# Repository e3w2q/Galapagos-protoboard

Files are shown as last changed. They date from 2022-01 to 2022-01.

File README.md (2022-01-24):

# Galapagos Protoboard

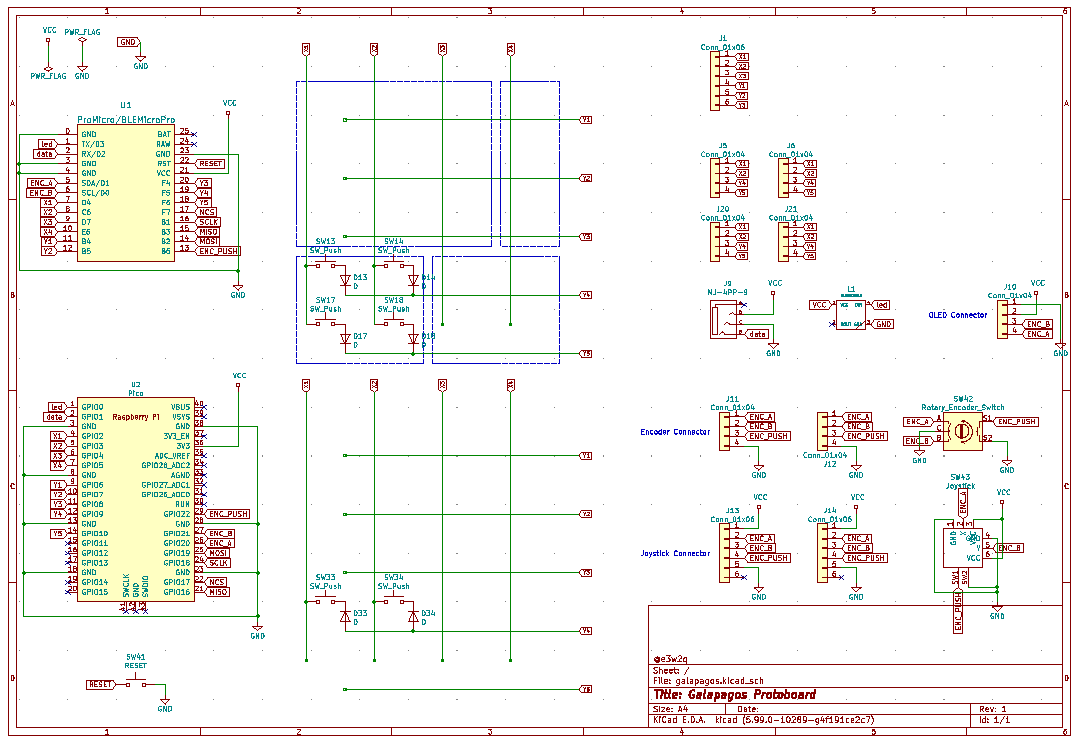
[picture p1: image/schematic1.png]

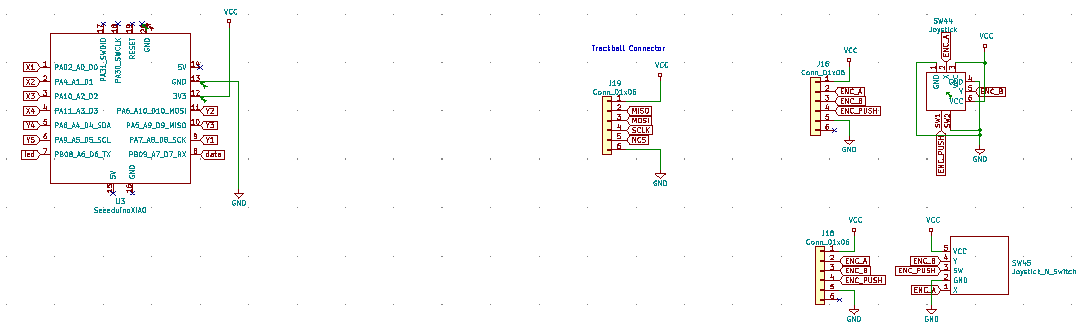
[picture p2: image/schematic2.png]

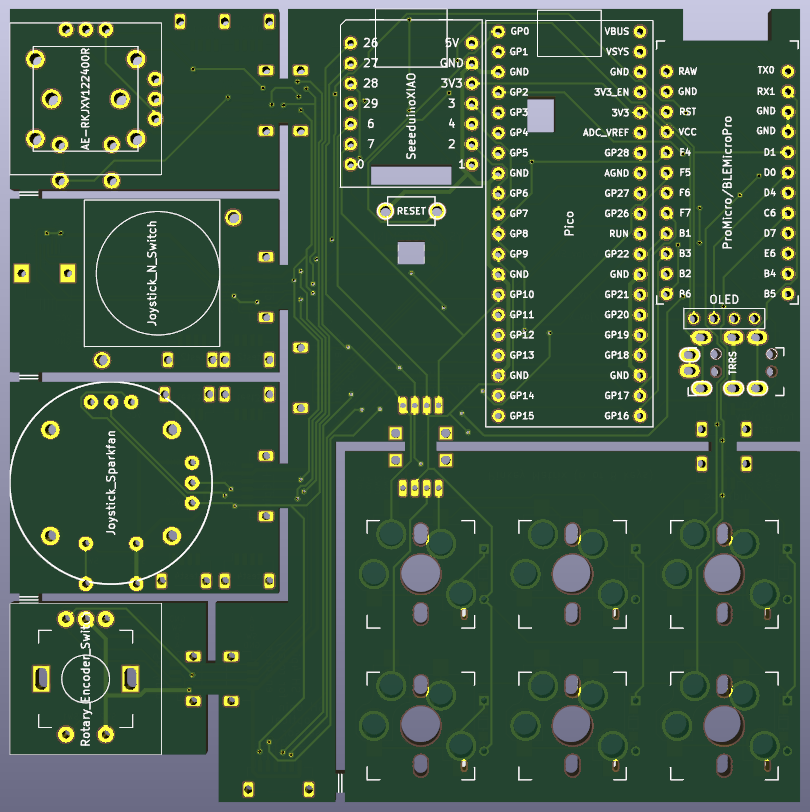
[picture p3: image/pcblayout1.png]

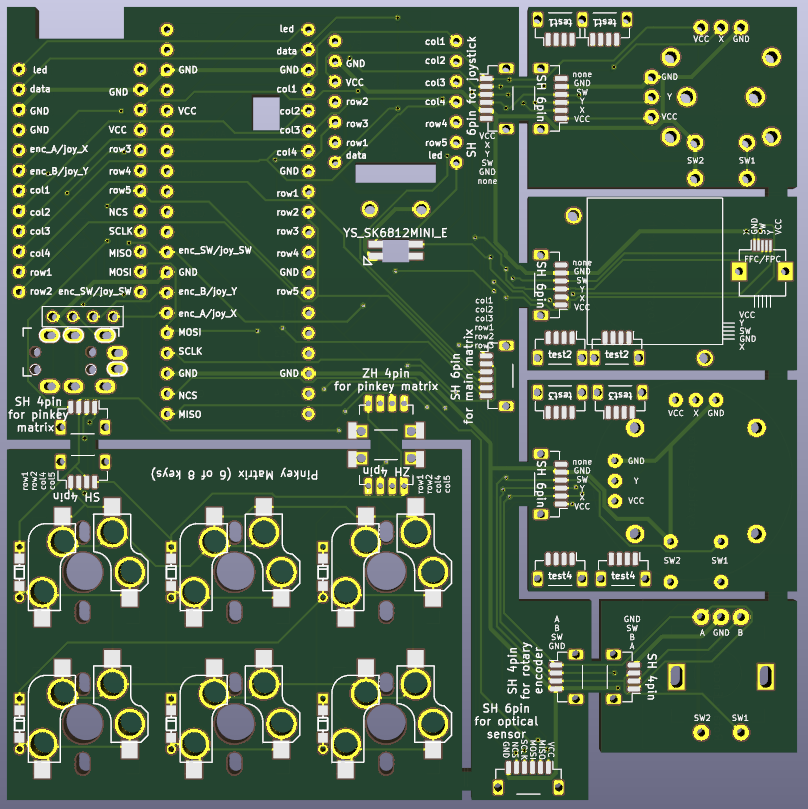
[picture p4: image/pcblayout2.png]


## Important point

All functions have not yet been verified on an actual device.

The microcontroller is one of the following: Pro Micro, Raspberry Pi Pico, or Xiao RP2040.

The key matrix is using duplex matrix.

You can use a rotary encoder or a joystick.

The joystick is one of the following:  ALPS RKJXV122400R, Nintendo Switch Joystick for Joy-Cons,  or Sparkfan joystick.

You may be able to use a trackball.

## Pin assign

### Key switch

| | Pro Micro | Raspberry Pi Pico | Xiao RP2040 |
| --- | --- | --- | --- |
| Upper left key switch | F5 to D4  | GP9 to GP2 | GP6 to GP26 |
| Lower left key switch | F5 to C6  | GP9 to GP3 | GP6 to GP27 |
| Upper middle key switch | D4 to F6  | GP2 to GP10 | GP26 to GP7 |
| Lower middle key switch | C6 to F6  | GP3 to GP10 | GP27 to GP7 |
| Upper right key switch  | D4 to F5  | GP2 to GP9 | GP26 to GP6 |
| Lower right key switch  | C6 to F5  | GP3 to GP9 | GP27 to GP6 |

### Rotary Encoder

| | Pro Micro | Raspberry Pi Pico | Xiao RP2040 |
| --- | --- | --- | --- |
| A | D1 | GP20 | No assign |
| B | D0 | GP21 | No assign |
| Push switch | B6 | GP22 | No assign |

### Joystick

| | Pro Micro | Raspberry Pi Pico | Xiao RP2040 |
| --- | --- | --- | --- |
| Horizontal  | D1 | GP20 | No assign |
| Vertical | D0 | GP21 | No assign |
| Push switch | B6 | GP22 | No assign |

### Trackball

| | Pro Micro | Raspberry Pi Pico | Xiao RP2040 |
| --- | --- | --- | --- |
| MISO | B3 | GP16 | No assign |
| MOSI | B2 | GP19 | No assign |
| SCLK | B1 | GP18 | No assign |
| NCS | F7 | GP17 | No assign |

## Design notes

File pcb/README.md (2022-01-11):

# Galapagos Protoboard

## Schematic
[Schematic PDF](../image/ukiha.pdf?raw=true)
Schematic

## PCB Layout
PCB Layout
PCB Layout

## Acrylic Layout
Acrylic Layout

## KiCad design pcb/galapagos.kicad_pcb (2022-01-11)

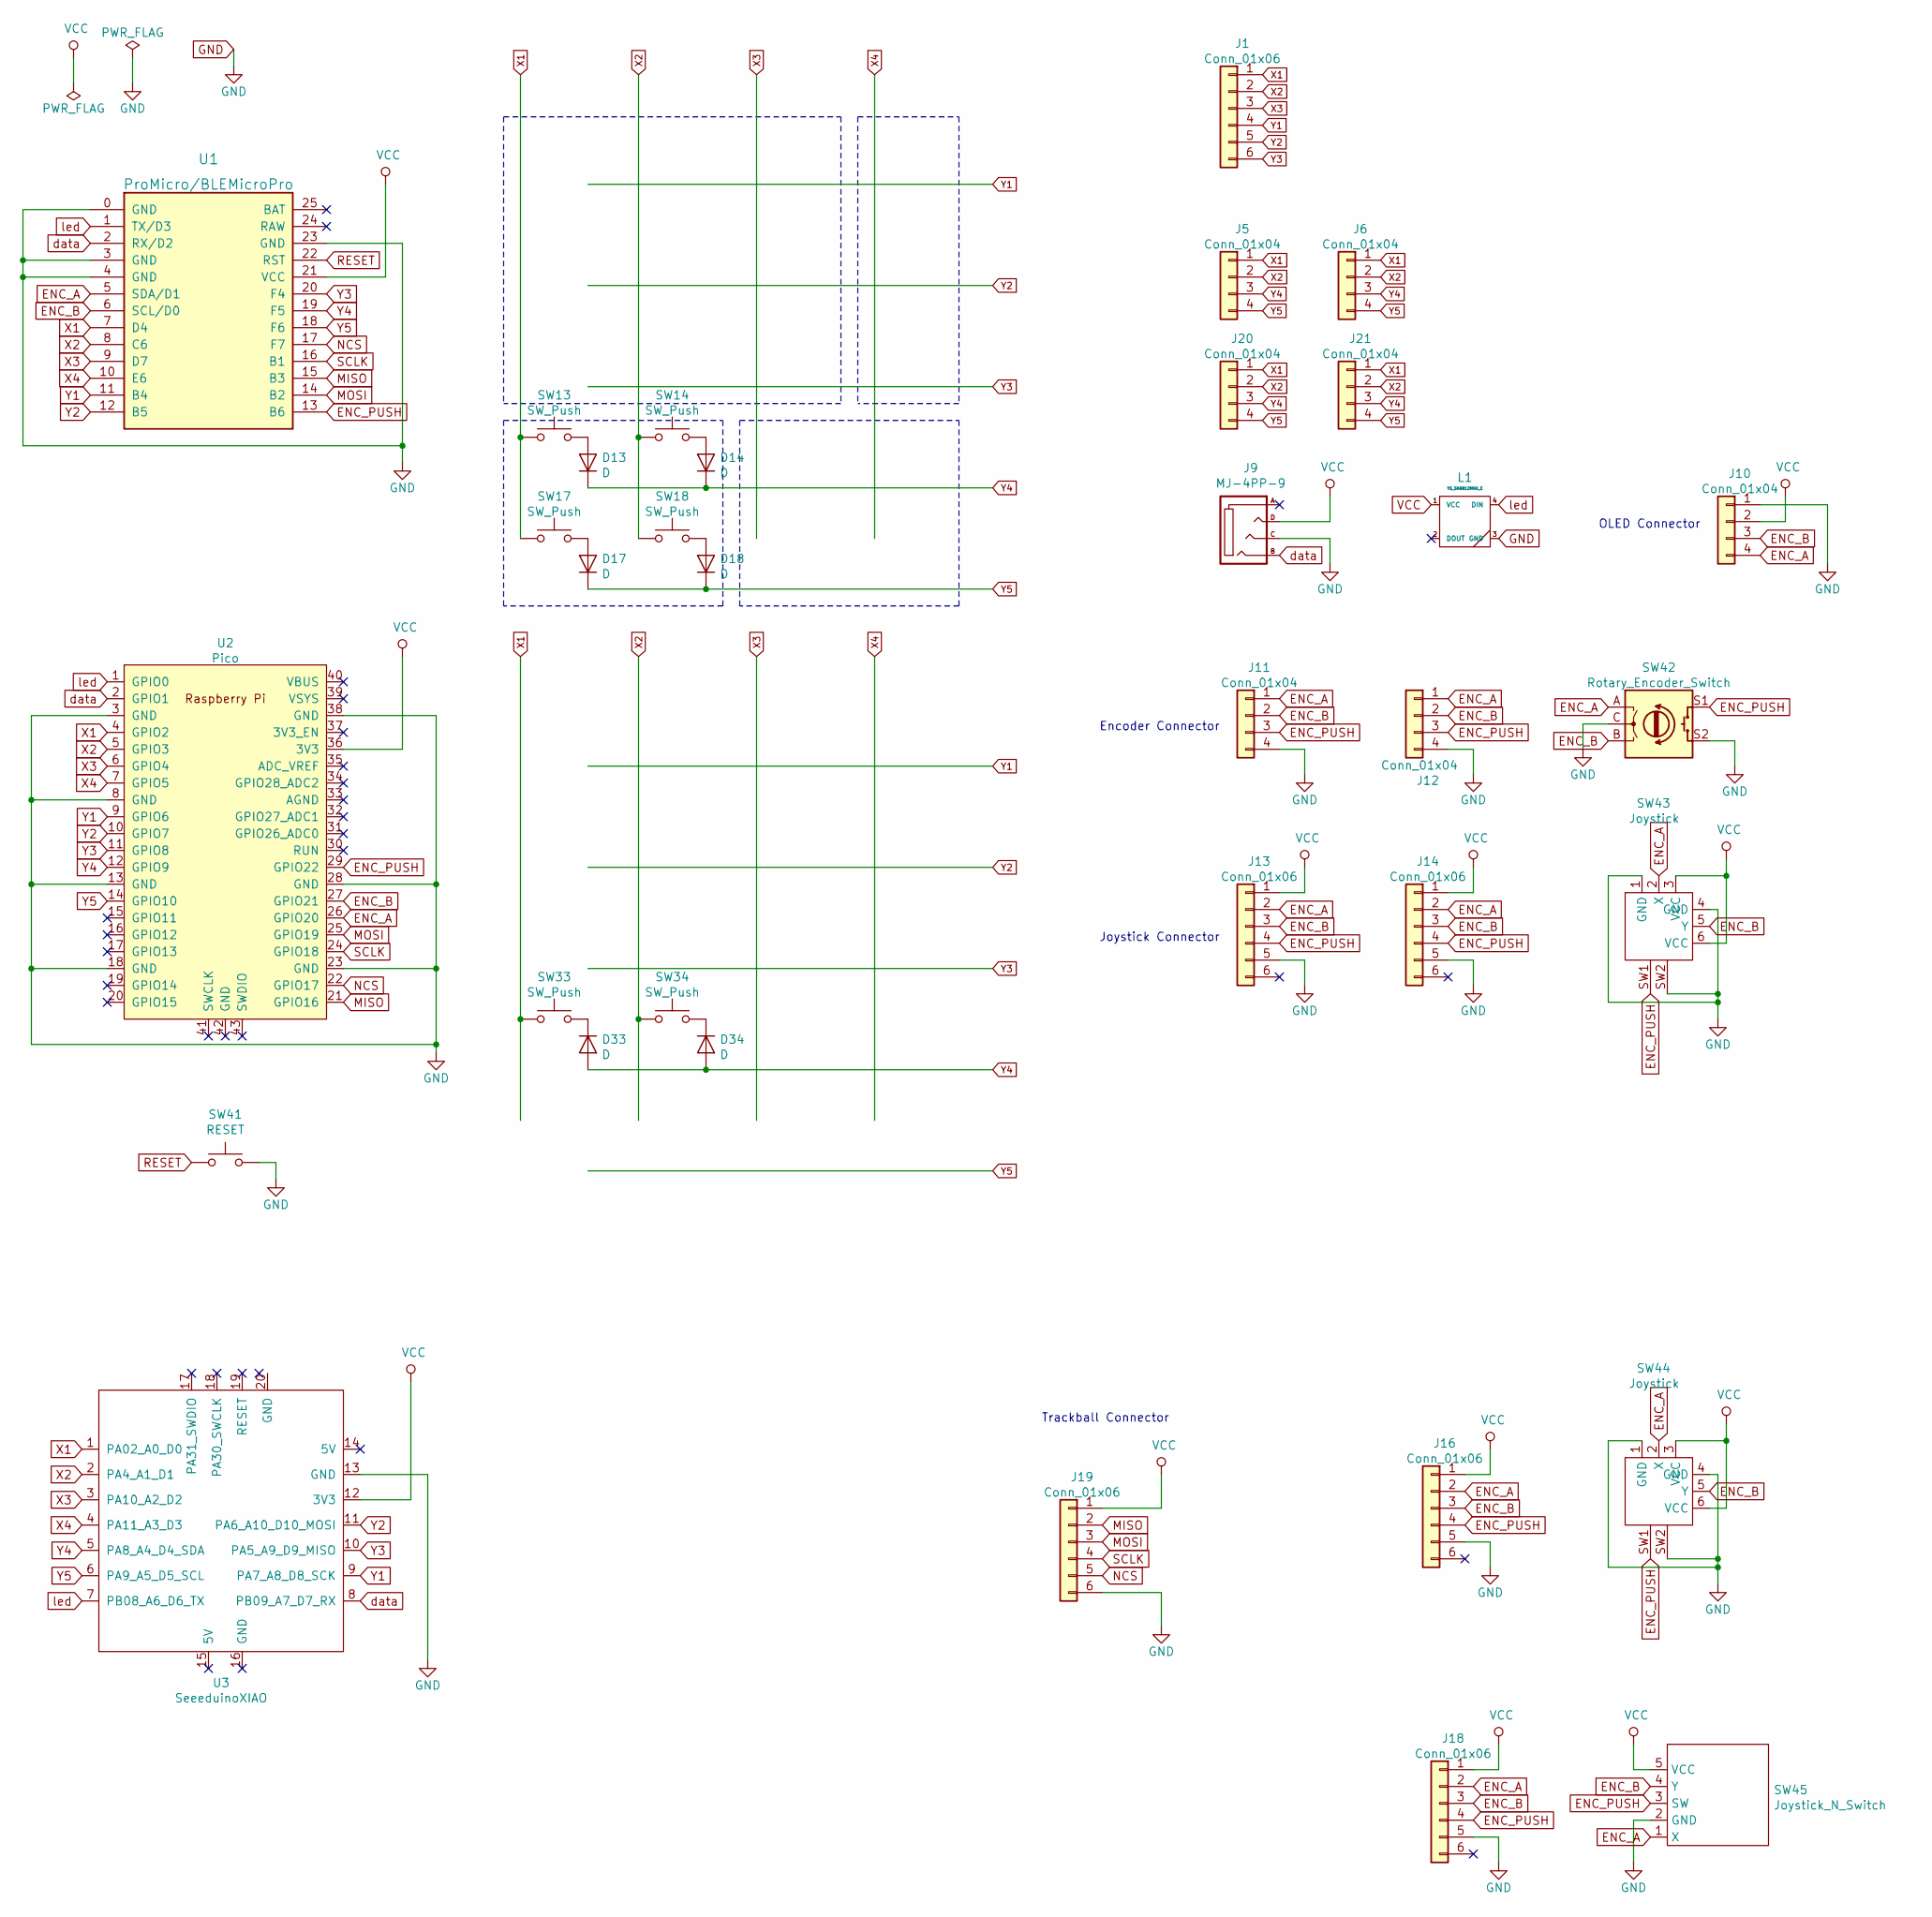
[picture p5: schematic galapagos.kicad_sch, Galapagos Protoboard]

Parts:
D13, D14, D17, D18, D33, D34: D; diode_TH_SMD_rev3
J1, J13, J14, J16, J18, J19: Conn_01x06; JST_SH_BM03B-SRSS-TB_1x06-1MP_P1.00mm_Vertical
J5, J6, J11, J12: Conn_01x04; JST_SH_BM03B-SRSS-TB_1x04-1MP_P1.00mm_Vertical
J9: MJ-4PP-9; MJ-4PP-9_reversible
J10: Conn_01x04; PinHeader_1x04_P2.54mm_Vertical
J20, J21: Conn_01x04; JST_ZH_1x04_P1.50mm_Vertical
L1: YS_SK6812MINI_E; YS-SK6812MINI-E
SW13, SW14, SW17, SW18, SW33, SW34: SW_Push; CherryMX_MidHeight_Choc_Hotswap_rev8_test
SW41: RESET; ResetSW
SW42: Rotary_Encoder_Switch; RotaryEncoder_Alps_EC11E-Switch_Vertical_H20mm_rev2
SW43: Joystick; Joystick_AE-RKJXV122400R
SW44: Joystick; Joystick_Sparkfan
SW45: Joystick_N_Switch
U1: ProMicro/BLEMicroPro; ArduinoProMicro_ConThrough
U2: Pico; RPi_Pico_SMD_TH_rev3
U3: SeeeduinoXIAO; Seeeduino XIAO RP2040

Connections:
ENC_A: J10.4, J11.1, J12.1, J13.2, J14.2, J16.2, J18.2, SW42.A, SW43.2 (X), SW44.2 (X), SW45.1 (X), U1.5 (SDA/D1), U2.26 (GPIO20)
ENC_B: J10.3, J11.2, J12.2, J13.3, J14.3, J16.3, J18.3, SW42.B, SW43.5 (Y), SW44.5 (Y), SW45.4 (Y), U1.6 (SCL/D0), U2.27 (GPIO21)
ENC_PUSH: J11.3, J12.3, J13.4, J14.4, J16.4, J18.4, SW42.S1, SW43.SW1, SW44.SW1, SW45.3 (SW), U1.13 (B6), U2.29 (GPIO22)
GND: J9.C, J10.1, J11.4, J12.4, J13.5, J14.5, J16.5, J18.5, J19.6, L1.3 (GND), SW41.2, SW42.C, SW42.S2, SW43.1 (GND), SW43.4 (GND), SW43.SW2, SW44.1 (GND), SW44.4 (GND), SW44.SW2, SW45.2 (GND), U1.0 (GND), U1.3 (GND), U1.4 (GND), U1.23 (GND), U2.3 (GND), U2.8 (GND), U2.13 (GND), U2.18 (GND), U2.23 (GND), U2.28 (GND), U2.38 (GND), U3.13 (GND)
MISO: J19.2, U1.15 (B3), U2.21 (GPIO16)
MOSI: J19.3, U1.14 (B2), U2.25 (GPIO19)
NCS: J19.5, U1.17 (F7), U2.22 (GPIO17)
unnamed: D13.2 (A), SW13.2
unnamed: D14.2 (A), SW14.2
unnamed: D17.2 (A), SW17.2
unnamed: D18.2 (A), SW18.2
unnamed: D33.1 (K), SW33.2
unnamed: D34.1 (K), SW34.2
RESET: SW41.1, U1.22 (RST)
SCLK: J19.4, U1.16 (B1), U2.24 (GPIO18)
VCC: J9.D, J10.2, J13.1, J14.1, J16.1, J18.1, J19.1, L1.1 (VCC), SW43.3 (VCC), SW43.6 (VCC), SW44.3 (VCC), SW44.6 (VCC), SW45.5 (VCC), U1.21 (VCC), U2.36 (3V3), U3.12 (3V3)
X1: J1.1, J5.1, J6.1, J20.1, J21.1, SW13.1, SW17.1, SW33.1, U1.7 (D4), U2.4 (GPIO2), U3.1 (PA02_A0_D0)
X2: J1.2, J5.2, J6.2, J20.2, J21.2, SW14.1, SW18.1, SW34.1, U1.8 (C6), U2.5 (GPIO3), U3.2 (PA4_A1_D1)
X3: J1.3, U1.9 (D7), U2.6 (GPIO4), U3.3 (PA10_A2_D2)
X4: U1.10 (E6), U2.7 (GPIO5), U3.4 (PA11_A3_D3)
Y1: J1.4, U1.11 (B4), U2.9 (GPIO6), U3.9 (PA7_A8_D8_SCK)
Y2: J1.5, U1.12 (B5), U2.10 (GPIO7), U3.11 (PA6_A10_D10_MOSI)
Y3: J1.6, U1.20 (F4), U2.11 (GPIO8), U3.10 (PA5_A9_D9_MISO)
Y4: D13.1 (K), D14.1 (K), D33.2 (A), D34.2 (A), J5.3, J6.3, J20.3, J21.3, U1.19 (F5), U2.12 (GPIO9), U3.5 (PA8_A4_D4_SDA)
Y5: D17.1 (K), D18.1 (K), J5.4, J6.4, J20.4, J21.4, U1.18 (F6), U2.14 (GPIO10), U3.6 (PA9_A5_D5_SCL)
data: J9.B, U1.2 (RX/D2), U2.2 (GPIO1), U3.8 (PB09_A7_D7_RX)
led: L1.4 (DIN), U1.1 (TX/D3), U2.1 (GPIO0), U3.7 (PB08_A6_D6_TX)

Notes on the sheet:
Trackball Connector
Encoder Connector
Joystick Connector
OLED Connector

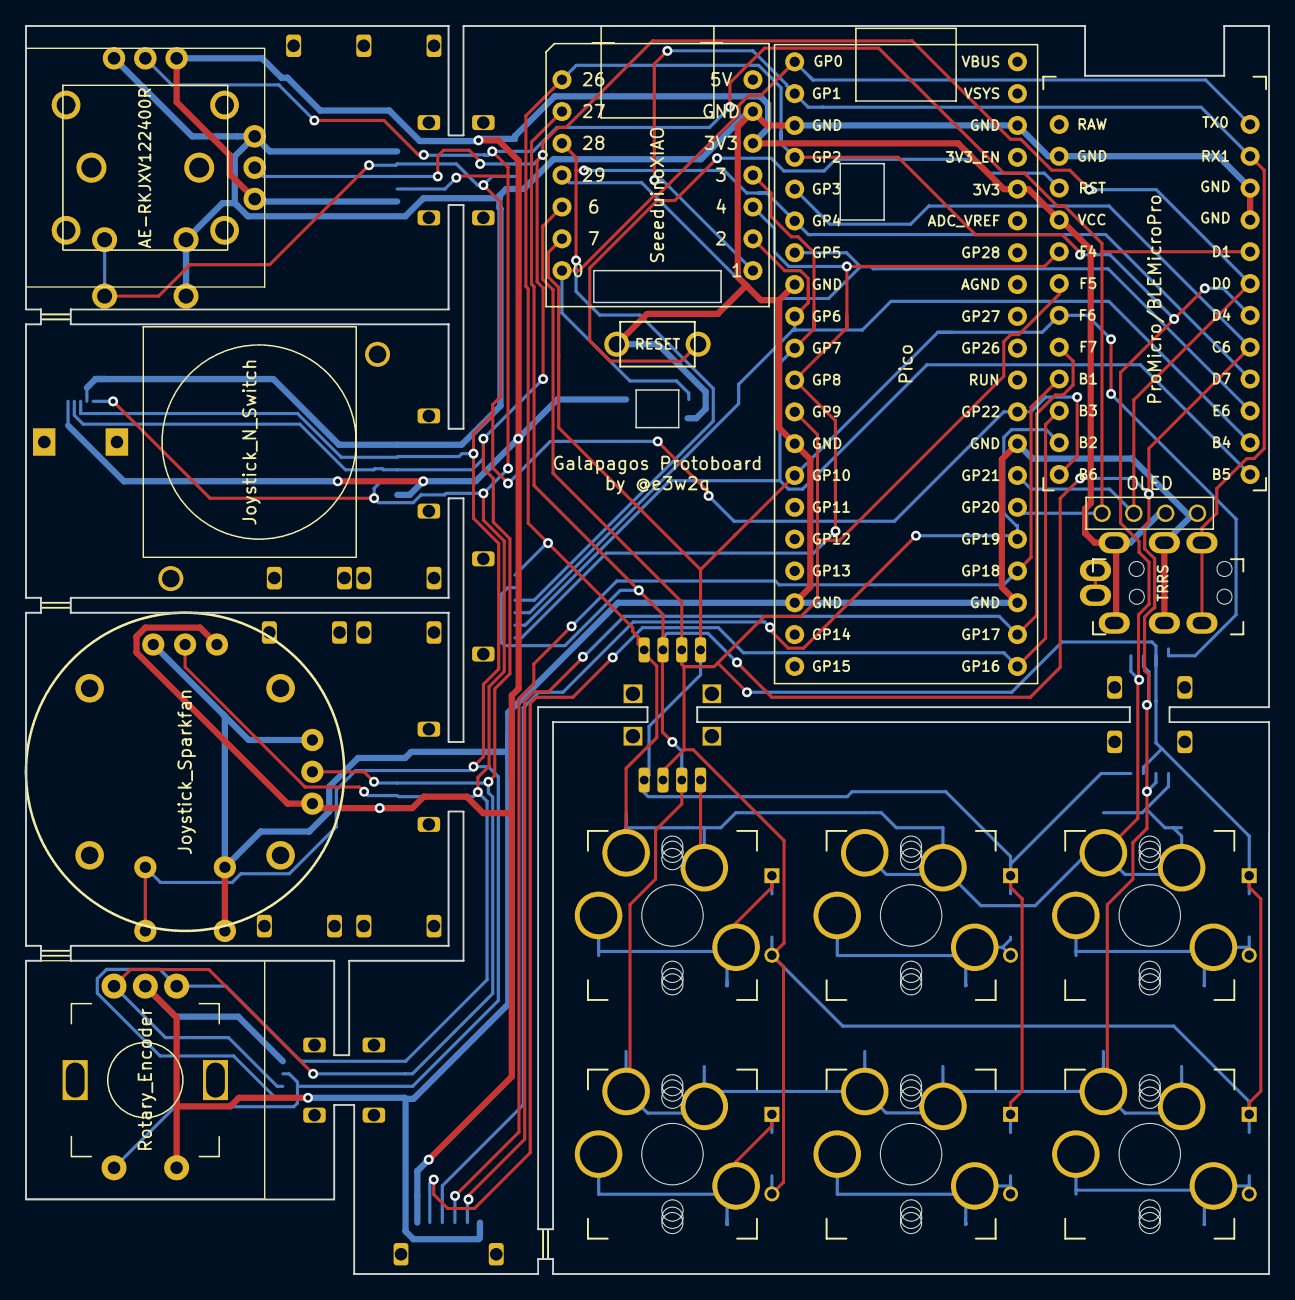
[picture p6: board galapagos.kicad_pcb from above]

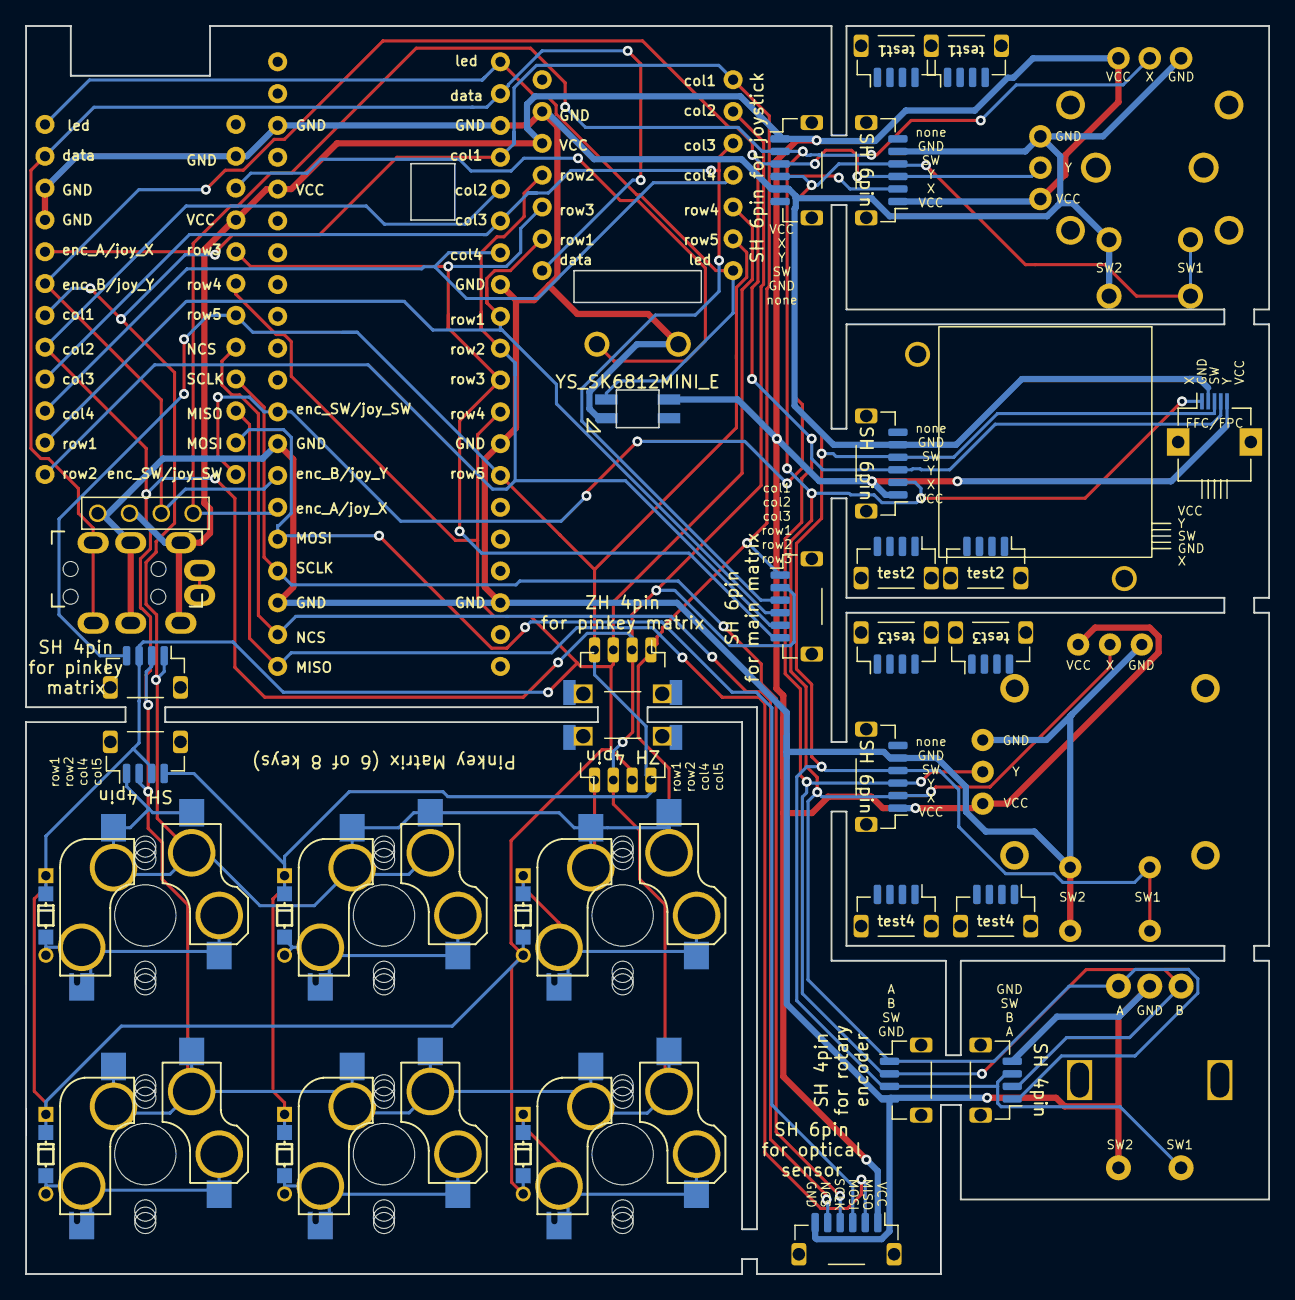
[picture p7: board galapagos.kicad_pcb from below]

Board: 2 copper layers, 99.2 x 99.6 mm, 35 parts (12 on the bottom side), 27 nets.
